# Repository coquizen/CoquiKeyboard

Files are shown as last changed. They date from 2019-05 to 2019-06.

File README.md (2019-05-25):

<!--
*** Thanks for checking out this README Template. If you have a suggestion that would
*** make this better please fork the repo and create a pull request or simple open
*** an issue with the tag "enhancement".
*** Thanks again! Now go create something AMAZING! :D
-->

<!-- PROJECT SHIELDS -->
[][license-url]

<!-- PROJECT LOGO -->
<br />
<p align="center">
  <a href="https://github.com/CaninoDev/Coqui">
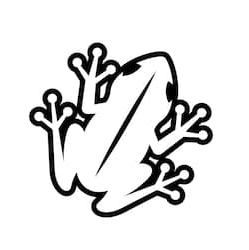
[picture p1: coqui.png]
    
  </a>

  <h3 align="center">Coquí Keyboard</h3>

  <p align="center">
    A 40% compact keyboard with a full complement of alphas, including punctuation and symbols.
    <br />
    <a href="https://github.com/CaninoDev/Coqui"><strong>Explore the docs »</strong></a>
    <br />
    <br />
    <a href="https://github.com/othneildrew/Best-README-Template">View Demo</a>
    ·
    <a href="https://github.com/othneildrew/Best-README-Template/issues">Report Bug</a>
    ·
    <a href="https://github.com/othneildrew/Best-README-Template/issues">Request Feature</a>
  </p>
</p>

<!-- TABLE OF CONTENTS -->
## Table of Contents

- [Table of Contents](#table-of-contents)
- [About The Project](#about-the-project)
  - [Built With](#built-with)
- [Getting Started](#getting-started)
  - [Prerequisites](#prerequisites)
  - [Installation](#installation)
- [Usage](#usage)
- [Contributing](#contributing)
- [License](#license)
- [Contact](#contact)
- [Acknowledgements](#acknowledgements)

<!-- ABOUT THE PROJECT -->
## About The Project
Initial version 
[Keyboard Layout](https://github.com/CaninoDev/CoquiKeyboard)
 Finalized version
[Keyboard_Layout_Finalized](https://i.imgur.com/WaaT3K5.png)
The coquí is a species of frog native to the island of Puerto Rico. Typically, they are no larger than a penny. They are so named for the loud mating call, _co-kee_. Similarly, this keyboard is a compact 40% keyboard with an extra column of two keys on the right intended for volume control. This keyboard is loosely based on  [Clueboard](https://clueboard.co/)

### Built With
The initial design was created with the help of [Keyboard Layout Editor](www.keyboard-layout-editor.com/) with input from @alexicon and @critray.
The schematic and pcb was created in [Kicad](http://kicad-pcb.org), an open source software.

<!-- GETTING STARTED -->
## Getting Started

_PLACEHOLDER_
### Prerequisites

_PLACEHOLDER_

### Installation

_PLACEHOLDER_
<!-- USAGE EXAMPLES -->
## Usage

_PLACEHOLDER_
<!-- CONTRIBUTING -->
## Contributing

_PLACEHOLDER_
<!-- LICENSE -->
## License

Distributed under the GPL License. See `LICENSE` for more information.

<!-- CONTACT -->
## Contact

<!-- ACKNOWLEDGEMENTS -->
## Acknowledgements

<!-- MARKDOWN LINKS & IMAGES -->

[license-shield]: https://img.shields.io/badge/license-GPL-blue.svg?style=flat-square
[license-url]: https://choosealicense.com/licenses/mit
[keyboard-layout]: https://i.imgur.com/pRL0Bjm.png\
[keyboard-layout2]: https://i.imgur.com/WaaT3K5.png

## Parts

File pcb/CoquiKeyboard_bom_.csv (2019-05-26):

Component | Description | Part | References | Value | Footprint | Quantity Per PCB | Datasheet | LCSC Link
1 | Unpolarized capacitor, small symbol | C_Small | C1 C2 C3 | 0.1uF | C_0805_2012Metric | 3 | ~ | https://lcsc.com/product-detail/Others_CCTC-TCC0805X7R104M500DT_C360619.html
2 | Unpolarized capacitor, small symbol | C_Small | C4 | 10uF | C_0805_2012Metric | 1 | ~ | https://lcsc.com/product-detail/Others_Samsung-Electro-Mechanics_CL21A106KQFNNNE_Samsung-Electro-Mechanics-CL21A106KQFNNNE_C307525.html
3 | Unpolarized capacitor, small symbol | C_Small | C7 | 1uF | C_0805_2012Metric | 1 | ~ | https://lcsc.com/product-detail/Multilayer-Ceramic-Capacitors-MLCC-SMD-SMT_1uF-105-5-25V_C106837.html
4 | Unpolarized capacitor, small symbol | C_Small | C5 C6 | 22pF | C_0805_2012Metric | 2 | ~ | https://lcsc.com/product-detail/New-Arrivals_CCTC-TCC0805COG220J500BT_C376875.html
5 | Diode, small symbol | D_Small | D1 D2 D3 D4 D5 D6 D7 D8 D9 D10 D11 D12 D13 D14 D15 D16 D17 D18 D19 D20 D21 D22 D23 D24 D25 D26 D27 D28 D29 D30 D31 D32 D33 D34 D35 D36 D37 D38 D39 D40 D41 D42 D43 D44 D45 D46 D47 D48 D49 D50 D51 D52 D53 D54 | D | D_SOD-123 | 54 | ~ | https://lcsc.com/product-detail/Switching-Diode_IN4148W_C181134.html
6 | Resettable fuse, polymeric positive temperature coefficient | Polyfuse | F1 | 500mA | Fuse_1206_3216Metric | 1 | ~ | https://lcsc.com/product-detail/Others_Littelfuse_1206L050YR_Littelfuse-1206L050YR_C163512.html
7 |  | MX-1.25U | MX16 MX41-1 MX45 MX46 MX49 MX50 | MX-1.25U | MXOnly-1.25U-NoLED | 6
8 |  | MX-1.25U-FLIPPED | MX42 | MX-1.25U | MXOnly-1.25U-NoLED | 1
9 |  | MX-1.75U | MX28 MX30 | MX-1.75U | MXOnly-1.75U-NoLED | 2
10 |  | MX-1U | MX1 MX2 MX3 MX4 MX5 MX6 MX7 MX8 MX9 MX10 MX11 MX12 MX13 MX14 MX17 MX18 MX19 MX20 MX21 MX22 MX23 MX24 MX25 MX26 MX27 MX31 MX32 MX33 MX34 MX35 MX36 MX37 MX38 MX39 MX40 MX41 MX44 MX51 MX52 MX53 | MX-1U | MXOnly-1U-NoLED | 40
11 |  | MX-1U-FLIPPED | MX15 MX29 MX42-1 MX43 MX54 | MX-1U | MXOnly-1U-NoLED | 5
12 |  | MX-2.25U | MX47 | MX-2.25U | MXOnly-2.25U-ReversedStabilizers-NoLED | 1
13 |  | MX-2.75U | MX48 | MX-2.75U | MXOnly-2.75U-ReversedStabilizers-NoLED | 1
14 | Resistor, small symbol | R_Small | R1 R4 | 10k | R_0805_2012Metric | 2 | ~ | https://lcsc.com/product-detail/Chip-Resistor-Surface-Mount_10KR-103-5_C115295.html
15 | Resistor, small symbol | R_Small | R2 R3 | 22 | R_0805_2012Metric | 2 | ~ | https://lcsc.com/product-detail/Chip-Resistor-Surface-Mount_Uniroyal-Elec-0805W8J0220T5E_C25295.html
16 |  | SW_Push-Switch | SW1 | SW_Push | SKQG-1155865 | 1 | ~ | https://lcsc.com/product-detail/Tactile-Switches_ALPS_SKQGABE010_5-2-5-2-1-5-1-57N_C115351.html
17 | 16MHz, 32kB Flash, 2.5kB SRAM, 1kB EEPROM, USB 2.0, TQFP-44 | ATmega32U4-AU | U1 | ATmega32U4-AU | TQFP-44_10x10mm_P0.8mm | 1 | http://ww1.microchip.com/downloads/en/DeviceDoc/Atmel-7766-8-bit-AVR-ATmega16U4-32U4_Datasheet.pdf | https://lcsc.com/product-detail/ATMEL-AVR_ATMEL_ATMEGA32U4-AU_ATMEGA32U4-AU_C44854.html
18 |  | USB-Mini-B_ LCSC-C46398 | USB1 | USB Mini | USB-Mini-B_ LCSC-C46398 | 1 |  | https://lcsc.com/product-detail/USB-Connectors_Jing-Extension-of-the-Electronic-Co-LCSC-MINI-5PFemale90Degree-plate-four-feet-copper-shell-LCPVinyl-High-tempe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
19 |  | Crystal_GND24_Small-Device | Y1 | 16MHz | Crystal_SMD_3225-4Pin_3.2x2.5mm | 1 | ~ | https://lcsc.com/product-detail/SMD-Crystals_EPSON_X1E000021011900_TSX-3225-16MHZ-12PF-10PPM_C89371.html
Component Groups: | 19
Component Count: | 126
Fitted Components: | 126
Number of PCBs: | 1
Total components: | 126
Schematic Version:
Schematic Date:
BoM Date: | 5/26/2019 14:05
Schematic Source: | E:\Desktop\Peioris Boards\pcb comms\CoquiKeyboard\pcb\CoquiKeyboard.sch
KiCad Version: | Eeschema (5.0.1)-4

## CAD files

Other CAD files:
CoquiPlate.blend

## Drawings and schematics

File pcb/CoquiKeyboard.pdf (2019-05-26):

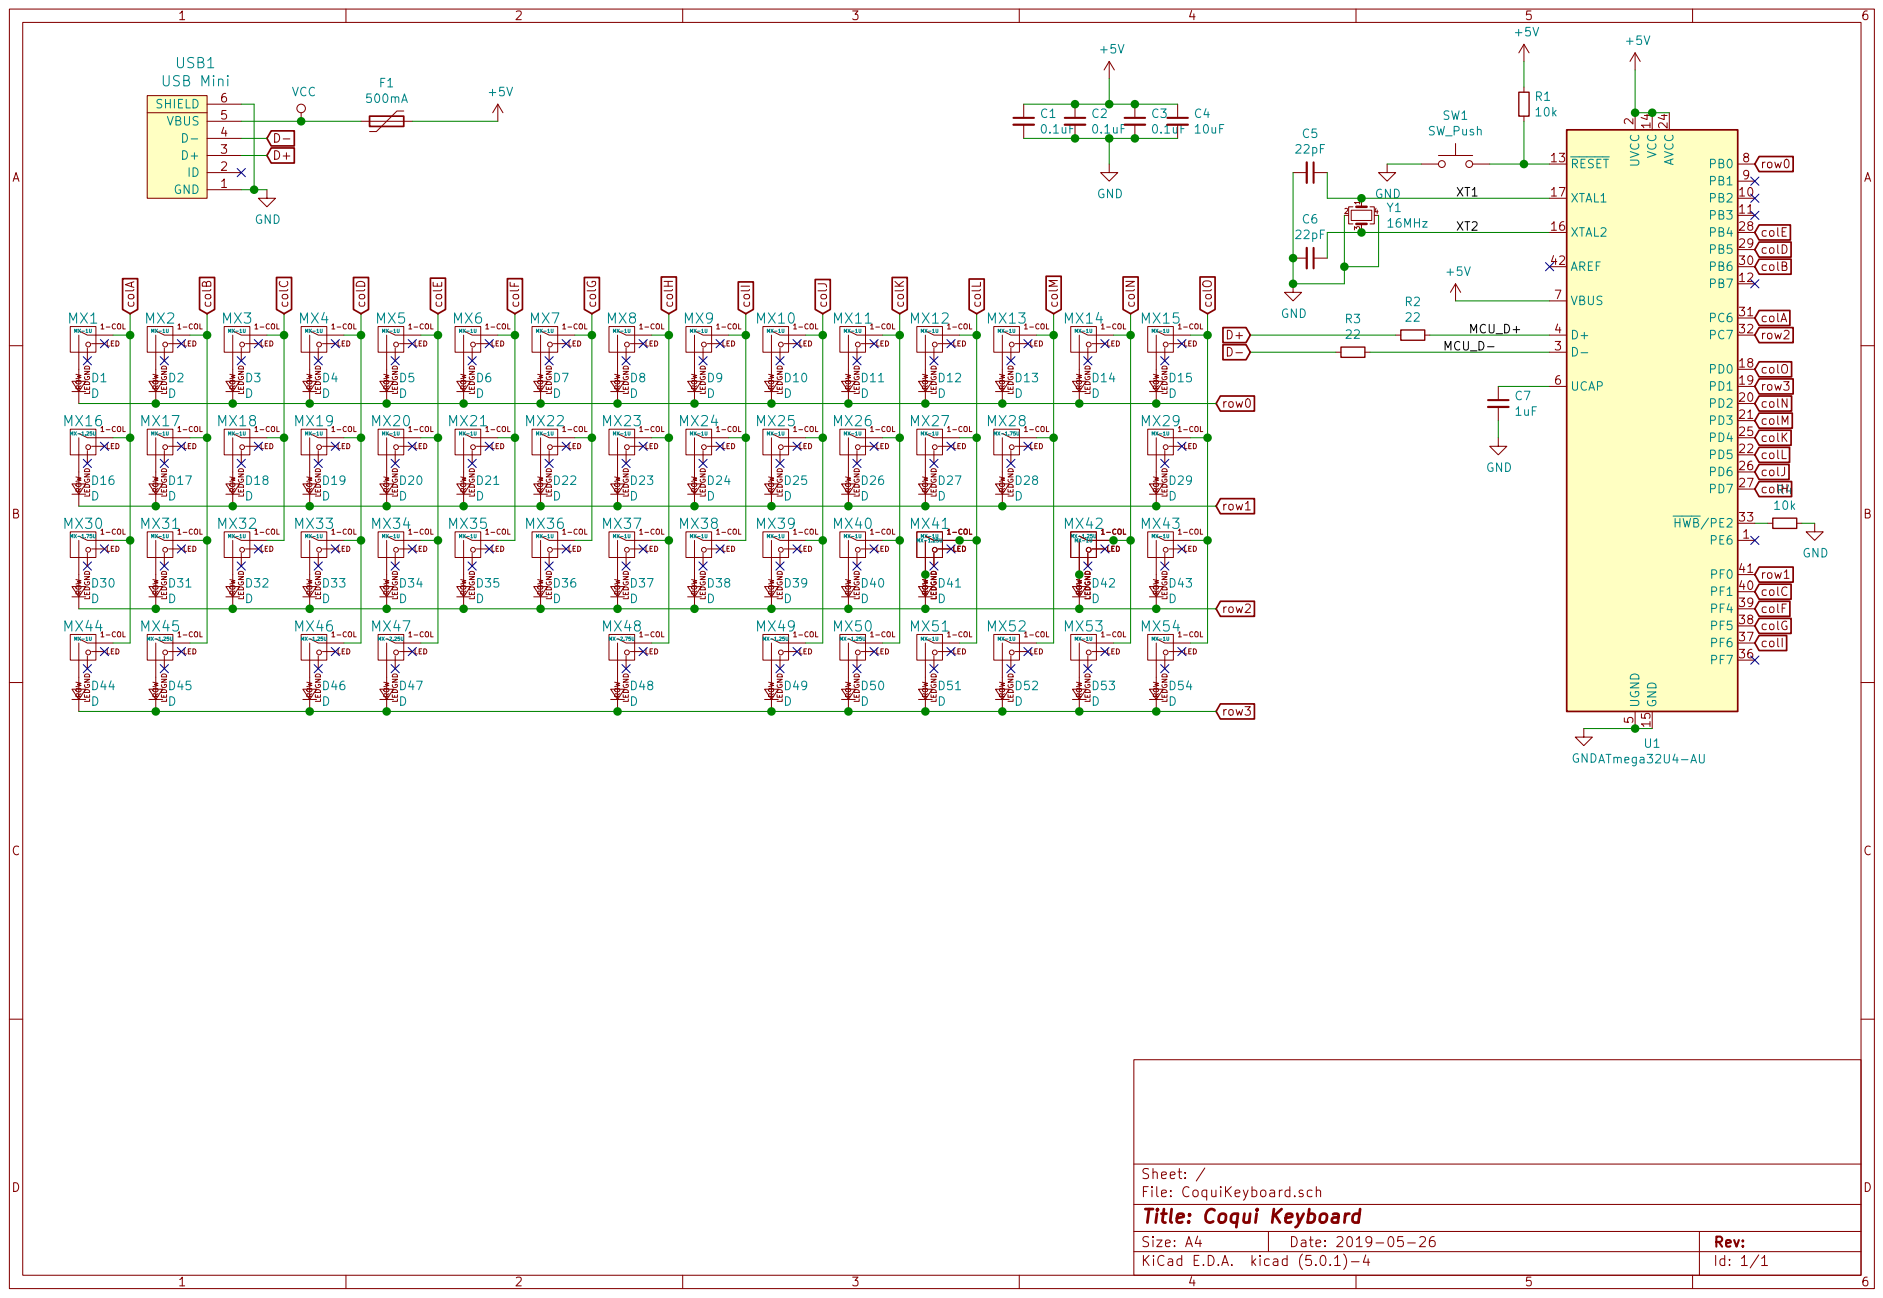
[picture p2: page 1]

2 PD2 20 PD3 21 PD5 22 AVCC 24 PD4 25 PD6 26 PD7 27 PB4 28 PB5 29 D- 3 PB6 30 PC6 31 PC7 32 HWB/PE2 33 PF7 36 PF6 37 PF5 38 PF4 39 D+ 4 PF1 40 PF0 41 AREF 42 UGND

File: CoquiKeyboard.sch Sheet: /
Id: 1/1 Title: Coqui Keyboard

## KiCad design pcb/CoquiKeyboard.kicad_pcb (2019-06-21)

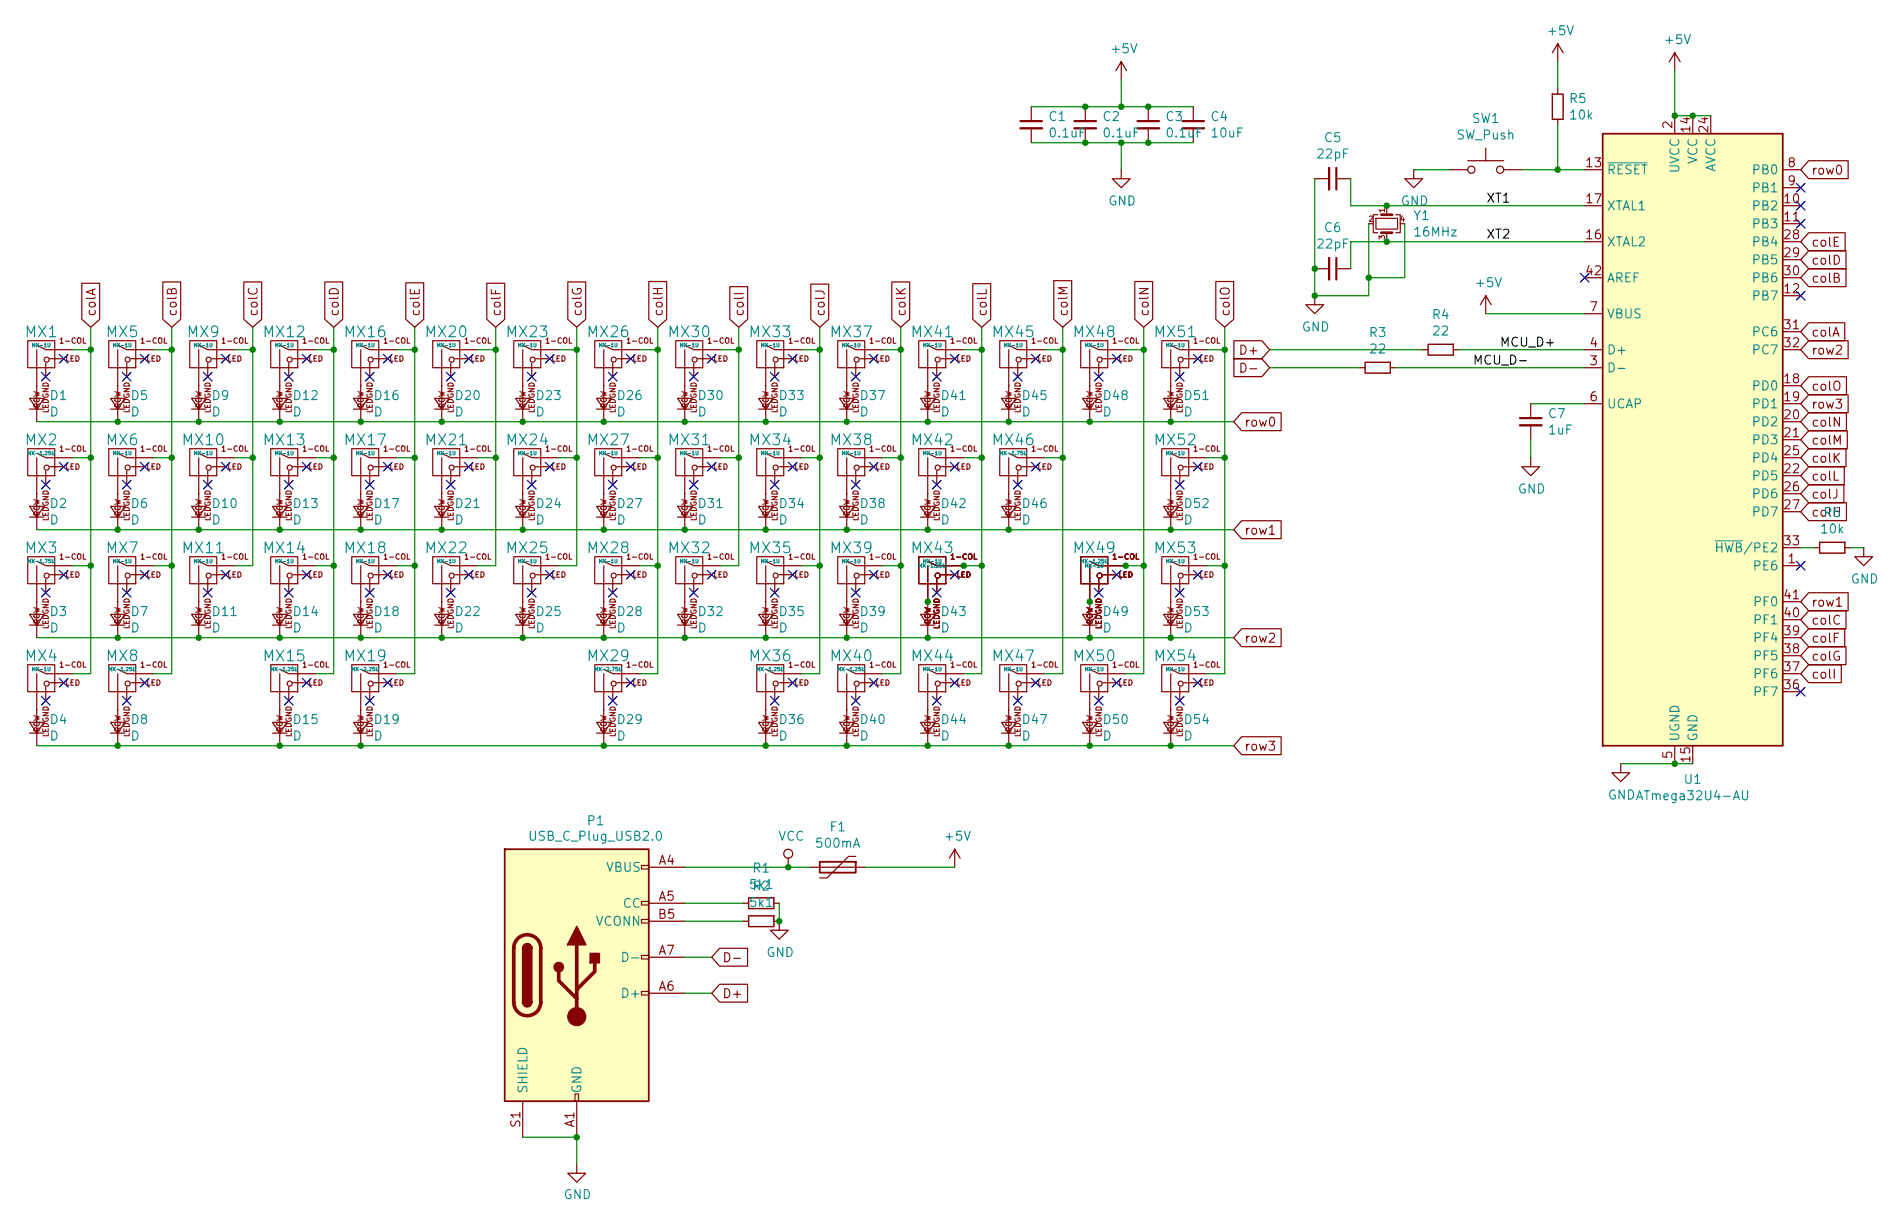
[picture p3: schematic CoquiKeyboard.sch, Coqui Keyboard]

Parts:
C1, C2, C3: 0.1uF; C_0805_2012Metric
C4: 10uF; C_0805_2012Metric
C5, C6: 22pF; C_0805_2012Metric
C7: 1uF; C_0805_2012Metric
D1, D2, D3, D4, D5, D6, D7, D8, D9, D10, D11, D12, D13, D14, D15, D16, D17, D18, D19, D20, D21, D22, D23, D24, D25, D26, D27, D28, D29, D30, D31, D32, D33, D34, D35, D36, D37, D38, D39, D40, D41, D42, D43, D44, D45, D46, D47, D48, D49, D50, D51, D52, D53, D54: D; D_SOD-123
F1: 500mA; Fuse_1206_3216Metric
MX1, MX4, MX5, MX6, MX7, MX9, MX10, MX11, MX12, MX13, MX14, MX16, MX17, MX18, MX20, MX21, MX22, MX23, MX24, MX25, MX26, MX27, MX28, MX30, MX31, MX32, MX33, MX34, MX35, MX37, MX38, MX39, MX41, MX42, MX42-1, MX43, MX44, MX45, MX47, MX48, MX50, MX51, MX52, MX53, MX54: MX-1U; MXOnly-1U-NoLED
MX2, MX8, MX15, MX36, MX40, MX41-1, MX49: MX-1.25U; MXOnly-1.25U-NoLED
MX3, MX46: MX-1.75U; MXOnly-1.75U-NoLED
MX19: MX-2.25U; MXOnly-2.25U-ReversedStabilizers-NoLED
MX29: MX-2.75U; MXOnly-2.75U-ReversedStabilizers-NoLED
P1: USB_C_Plug_USB2.0; USB_C_GCT_USB4085
R1, R2: 5k1; R_0805_2012Metric
R3, R4: 22; R_0805_2012Metric
R5, R6: 10k; R_0805_2012Metric
SW1: SW_Push; SKQG-1155865
U1: ATmega32U4-AU; TQFP-44_10x10mm_P0.8mm
Y1: 16MHz; Crystal_SMD_3225-4Pin_3.2x2.5mm

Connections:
+5V: C1.1, C2.1, C3.1, C4.1, F1.1, R5.1, U1.2 (UVCC), U1.7 (VBUS), U1.14 (VCC), U1.24 (AVCC), U1.34 (VCC), U1.44 (AVCC)
/MCU_D+: R4.1, U1.4 (D+)
/MCU_D-: R3.1, U1.3 (D-)
/XT1: C5.1, U1.17 (XTAL1), Y1.1
/XT2: C6.1, U1.16 (XTAL2), Y1.3
D+: P1.A6 (D+), R4.2
D-: P1.A7 (D-), R3.2
GND: C1.2, C2.2, C3.2, C4.2, C5.2, C6.2, C7.2, P1.A1 (GND), P1.A12 (GND), P1.B1 (GND), P1.B12 (GND), P1.S1 (SHIELD), R1.1, R2.1, R6.1, SW1.1, U1.5 (UGND), U1.15 (GND), U1.23 (GND), U1.35 (GND), U1.43 (GND), Y1.2, Y1.4
unnamed: C7.1, U1.6 (UCAP)
unnamed: D1.2 (A), MX1.2 (ROW)
unnamed: D2.2 (A), MX2.2 (ROW)
unnamed: D3.2 (A), MX3.2 (ROW)
unnamed: D4.2 (A), MX4.2 (ROW)
unnamed: D5.2 (A), MX5.2 (ROW)
unnamed: D6.2 (A), MX6.2 (ROW)
unnamed: D7.2 (A), MX7.2 (ROW)
unnamed: D8.2 (A), MX8.2 (ROW)
unnamed: D9.2 (A), MX9.2 (ROW)
unnamed: D10.2 (A), MX10.2 (ROW)
unnamed: D11.2 (A), MX11.2 (ROW)
unnamed: D12.2 (A), MX12.2 (ROW)
unnamed: D13.2 (A), MX13.2 (ROW)
unnamed: D14.2 (A), MX14.2 (ROW)
unnamed: D15.2 (A), MX15.2 (ROW)
unnamed: D16.2 (A), MX16.2 (ROW)
unnamed: D17.2 (A), MX17.2 (ROW)
unnamed: D18.2 (A), MX18.2 (ROW)
unnamed: D19.2 (A), MX19.2 (ROW)
unnamed: D20.2 (A), MX20.2 (ROW)
unnamed: D21.2 (A), MX21.2 (ROW)
unnamed: D22.2 (A), MX22.2 (ROW)
unnamed: D23.2 (A), MX23.2 (ROW)
unnamed: D24.2 (A), MX24.2 (ROW)
unnamed: D25.2 (A), MX25.2 (ROW)
unnamed: D26.2 (A), MX26.2 (ROW)
unnamed: D27.2 (A), MX27.2 (ROW)
unnamed: D28.2 (A), MX28.2 (ROW)
unnamed: D29.2 (A), MX29.2 (ROW)
unnamed: D30.2 (A), MX30.2 (ROW)
unnamed: D31.2 (A), MX31.2 (ROW)
unnamed: D32.2 (A), MX32.2 (ROW)
unnamed: D33.2 (A), MX33.2 (ROW)
unnamed: D34.2 (A), MX34.2 (ROW)
unnamed: D35.2 (A), MX35.2 (ROW)
unnamed: D36.2 (A), MX36.2 (ROW)
unnamed: D37.2 (A), MX37.2 (ROW)
unnamed: D38.2 (A), MX38.2 (ROW)
unnamed: D39.2 (A), MX39.2 (ROW)
unnamed: D40.2 (A), MX40.2 (ROW)
unnamed: D41.2 (A), MX41.2 (ROW)
unnamed: D42.2 (A), MX42.2 (ROW)
unnamed: D43.2 (A), MX41-1.2 (ROW), MX43.2 (ROW)
unnamed: D44.2 (A), MX44.2 (ROW)
unnamed: D45.2 (A), MX45.2 (ROW)
unnamed: D46.2 (A), MX46.2 (ROW)
unnamed: D47.2 (A), MX47.2 (ROW)
unnamed: D48.2 (A), MX48.2 (ROW)
unnamed: D49.2 (A), MX42-1.1 (ROW), MX49.1 (ROW)
unnamed: D50.2 (A), MX50.2 (ROW)
unnamed: D51.2 (A), MX51.1 (ROW)
unnamed: D52.2 (A), MX52.1 (ROW)
unnamed: D53.2 (A), MX53.1 (ROW)
unnamed: D54.2 (A), MX54.1 (ROW)
unnamed: P1.A5 (CC), R1.2
unnamed: P1.B5 (VCONN), R2.2
unnamed: R5.2, SW1.2, U1.13 (~RESET)
unnamed: R6.2, U1.33 (~HWB~/PE2)
VCC: F1.2, P1.A4 (VBUS), P1.A9 (VBUS), P1.B4 (VBUS), P1.B9 (VBUS)
colA: MX1.1 (COL), MX2.1 (COL), MX3.1 (COL), MX4.1 (COL), U1.31 (PC6)
colB: MX5.1 (COL), MX6.1 (COL), MX7.1 (COL), MX8.1 (COL), U1.30 (PB6)
colC: MX9.1 (COL), MX10.1 (COL), MX11.1 (COL), U1.40 (PF1)
colD: MX12.1 (COL), MX13.1 (COL), MX14.1 (COL), MX15.1 (COL), U1.29 (PB5)
colE: MX16.1 (COL), MX17.1 (COL), MX18.1 (COL), MX19.1 (COL), U1.28 (PB4)
colF: MX20.1 (COL), MX21.1 (COL), MX22.1 (COL), U1.39 (PF4)
colG: MX23.1 (COL), MX24.1 (COL), MX25.1 (COL), U1.38 (PF5)
colH: MX26.1 (COL), MX27.1 (COL), MX28.1 (COL), MX29.1 (COL), U1.27 (PD7)
colI: MX30.1 (COL), MX31.1 (COL), MX32.1 (COL), U1.37 (PF6)
colJ: MX33.1 (COL), MX34.1 (COL), MX35.1 (COL), MX36.1 (COL), U1.26 (PD6)
colK: MX37.1 (COL), MX38.1 (COL), MX39.1 (COL), MX40.1 (COL), U1.25 (PD4)
colL: MX41.1 (COL), MX41-1.1 (COL), MX42.1 (COL), MX43.1 (COL), MX44.1 (COL), U1.22 (PD5)
colM: MX45.1 (COL), MX46.1 (COL), MX47.1 (COL), U1.21 (PD3)
colN: MX42-1.2 (COL), MX48.1 (COL), MX49.2 (COL), MX50.1 (COL), U1.20 (PD2)
colO: MX51.2 (COL), MX52.2 (COL), MX53.2 (COL), MX54.2 (COL), U1.18 (PD0)
row0: D1.1 (K), D5.1 (K), D9.1 (K), D12.1 (K), D16.1 (K), D20.1 (K), D23.1 (K), D26.1 (K), D30.1 (K), D33.1 (K), D37.1 (K), D41.1 (K), D45.1 (K), D48.1 (K), D51.1 (K), U1.8 (PB0)
row1: D2.1 (K), D6.1 (K), D10.1 (K), D13.1 (K), D17.1 (K), D21.1 (K), D24.1 (K), D27.1 (K), D31.1 (K), D34.1 (K), D38.1 (K), D42.1 (K), D46.1 (K), D52.1 (K), U1.41 (PF0)
row2: D3.1 (K), D7.1 (K), D11.1 (K), D14.1 (K), D18.1 (K), D22.1 (K), D25.1 (K), D28.1 (K), D32.1 (K), D35.1 (K), D39.1 (K), D43.1 (K), D49.1 (K), D53.1 (K), U1.32 (PC7)
row3: D4.1 (K), D8.1 (K), D15.1 (K), D19.1 (K), D29.1 (K), D36.1 (K), D40.1 (K), D44.1 (K), D47.1 (K), D50.1 (K), D54.1 (K), U1.19 (PD1)

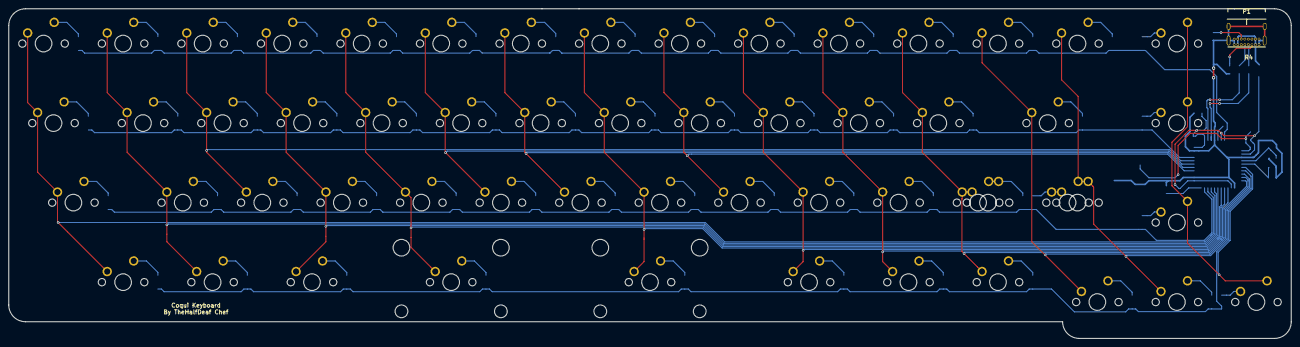
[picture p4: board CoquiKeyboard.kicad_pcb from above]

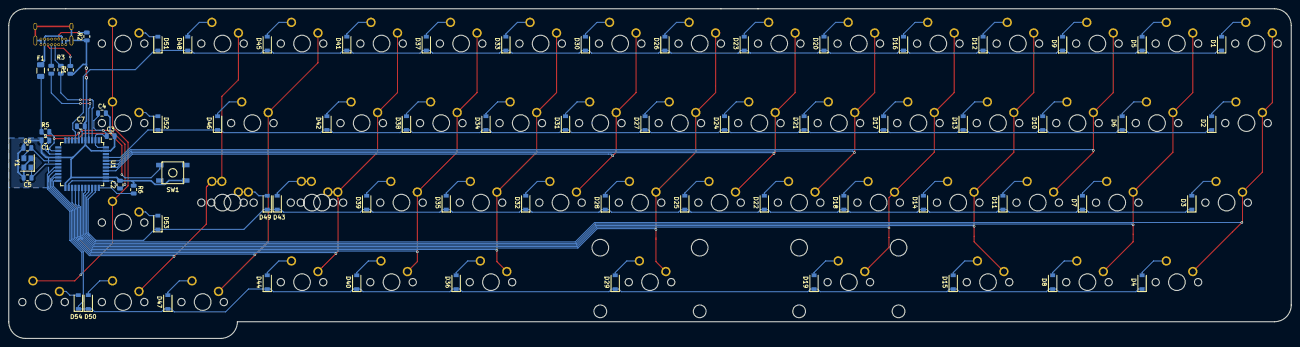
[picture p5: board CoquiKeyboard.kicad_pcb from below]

Board: 2 copper layers, 307.2 x 79.0 mm, 128 parts (71 on the bottom side), 87 nets.

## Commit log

2019-05-16 initialize KiCAD project
    [CoquiKeyboard.kicad_pcb, CoquiKeyboard.sch]
2019-05-16 add atmega32u4
    [CoquiKeyboard.sch]
2019-05-16 attach power and ground to mcu
    [CoquiKeyboard.sch]
2019-05-16 add resistors to USB pins
    [CoquiKeyboard.sch]
2019-05-16 add capacitors to UCAP
    [CoquiKeyboard.sch]
2019-05-17 add decoupling capacitors
    [CoquiKeyboard.sch]
2019-05-17 bind VBUS to 5V
    [CoquiKeyboard.sch]
2019-05-17 add crystal with load capacitors
    [CoquiKeyboard.sch]
2019-05-17 add pull up resistor between reset and +5v
    [CoquiKeyboard.sch]
2019-05-17 place global nets on the USB lines
    [CoquiKeyboard.sch]
2019-05-17 connect VBUS to Polyfuse
    [CoquiKeyboard.sch]
2019-05-17 add 50 switches
    [CoquiKeyboard.sch]
2019-05-17 connect anode of the diode of each row
    [CoquiKeyboard.sch]
2019-05-17 reformat schematics
    [CoquiKeyboard.sch]
2019-05-18 label components
    [CoquiKeyboard.sch]
2019-05-18 connect diodes to switches
    [CoquiKeyboard.sch]
2019-05-18 realignment of switches
    [CoquiKeyboard.sch]
2019-05-18 draw matrices
    [CoquiKeyboard.sch]
2019-05-18 label matrix
    [CoquiKeyboard.sch]
2019-05-18 assign footprint to schematics
    [CoquiKeyboard.sch]
2019-05-18 load netlist to create pcb
    [CoquiKeyboard.kicad_pcb]
2019-05-18 fix keysize error
    [CoquiKeyboard.kicad_pcb, CoquiKeyboard.sch]
2019-05-18 fix positioning of switches
    [CoquiKeyboard.sch]
2019-05-19 arrange switches to keyboard layout
    [CoquiKeyboard.kicad_pcb, CoquiKeyboard.sch]
2019-05-19 allign keyboard to grid
    [CoquiKeyboard.kicad_pcb]
2019-05-19 align resistors with their keys
    [CoquiKeyboard.kicad_pcb]
2019-05-20 clean up ratsnet
    [CoquiKeyboard.kicad_pcb, CoquiKeyboard.sch]
2019-05-22 refine some alignment
    [CoquiKeyboard.kicad_pcb]
2019-05-22 create PCB board outline
    [CoquiKeyboard.kicad_pcb]
2019-05-26 updated files
    [CoquiKeyboard.kicad_pcb, CoquiKeyboard.sch, CoquiKeyboard_bom_.csv]
2019-05-28 add logo as footprint
2019-05-28 update schematics to use with newer USB-C
    [CoquiKeyboard.kicad_pcb]
2019-05-28 replaced old footprint with new
    [CoquiKeyboard.kicad_pcb, CoquiKeyboard.sch]
2019-05-31 add plate files
    [CoquiPlate.blend]
2019-06-02 reconnect resistors and diodes to USB C
    [CoquiKeyboard.kicad_pcb, CoquiKeyboard.sch]
2019-06-06 create alternate location for usbc draft
    [CoquiReplacement.kicad_pcb]
2019-06-09 connected remainder of diodes, network closed
    [CoquiKeyboard.kicad_pcb]
2019-06-10 repopulate the BOM file
    [CoquiKeyboard-B_Cu.gbr, CoquiKeyboard-B_Mask.gbr, CoquiKeyboard-B_Paste.gbr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]
2019-06-13 complete board for prototyping
    [CoquiKeyboard-B_Cu.gbl, CoquiKeyboard-B_Mask.gbs, CoquiKeyboard-B_Paste.gbp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]
2019-06-21 readjust the pcb cutout to compensate for stab footprint
    [CoquiKeyboard.kicad_pcb]
2019-07-03 cleanup files
    [CoquiReplacement.kicad_pcb]
